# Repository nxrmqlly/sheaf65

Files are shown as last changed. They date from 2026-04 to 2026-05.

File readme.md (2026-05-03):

# sheaf65 🌊

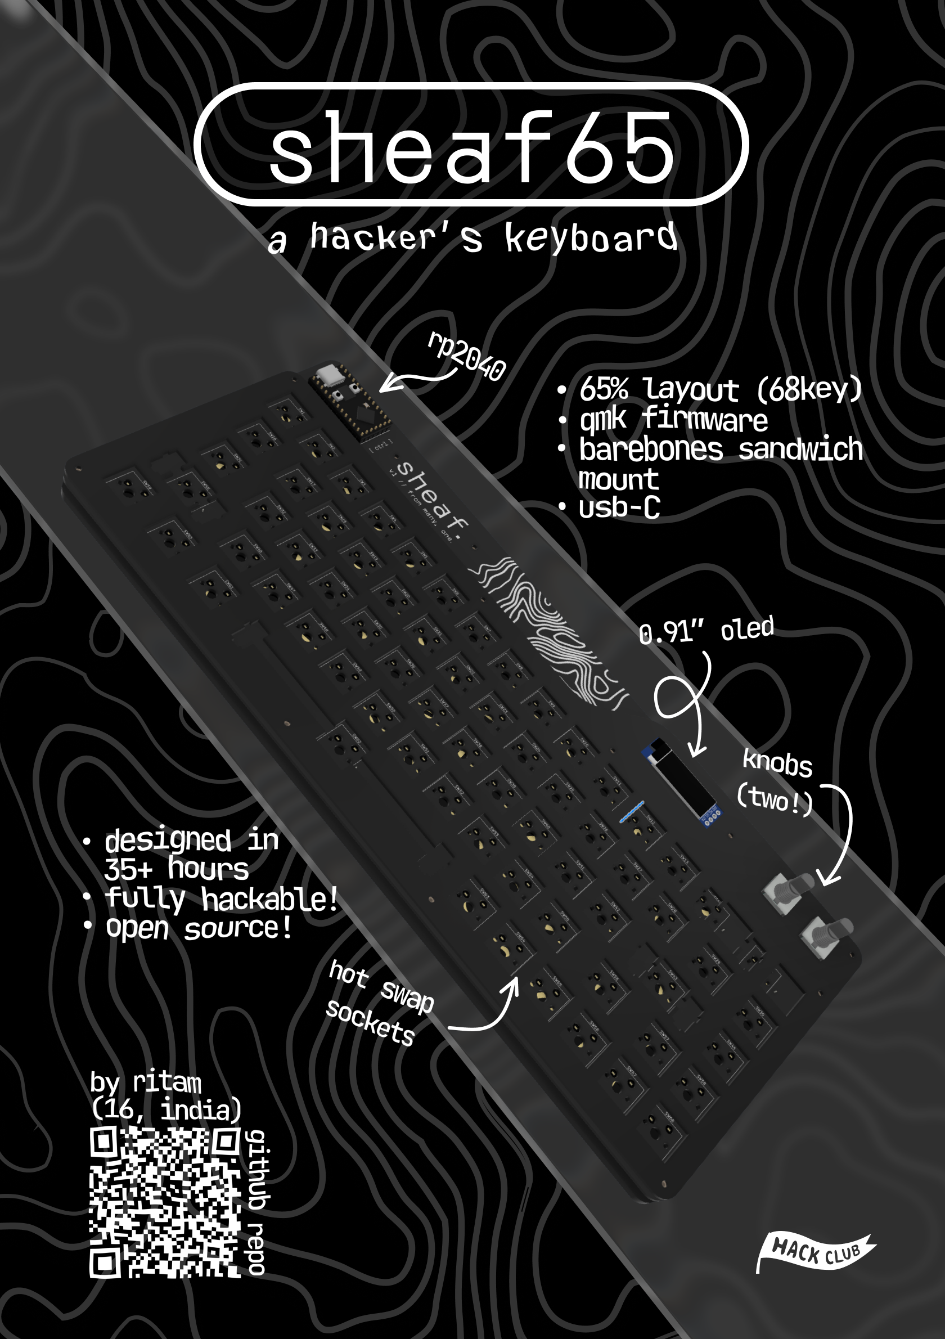
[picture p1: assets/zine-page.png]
hackclub magazine page


A barebones, hackable, opinionated, ansi 65% layout  keyboard. The `Backspace` key and the `Grave` key swapped due to personal preferences.

The Keyboard is designed to be very bare bones and it is basically 3 layers - The switchplate (top), The PCB (Middle),
and The Backplate (Bottom) - kind of like a sandwich mounted keyboard.

The switchplate ("plate") and the backplate are to be 3D printed and engineered.
The whole "sandwich" is held together with 10 M2x10mm brass spacers and one M2x6mm brass spacer.

I also took the liberty to add two knobs and an OLED display to the keyboard because... why not?

## TL;DR for busy people

A simple, hackable 65% keyboard
1. RP2040-powered
2. Fully Hotswap (TTC Pokayoke V2)
3. 0.91" OLED Screen
4. Dual Rotary Encoders (Knobs)
5. QMK firmware (VIA soon)
6. Sandwich Mounted (3-stacked-layer)

Built because I wanted something fun and unique... with knobs.

## Why?
I wanted a nice keyboard, and decided that making one for myself would be a fun challenge to pursue.
I wanted a unique yet sleek looking keyboard that somewhat resembles the idea of a through hole keybaord kit minus the ugly visible diodes.
Also, no such THT keyboard kit did hotswap sockets (I know the sockets are SMD but you get me) so there's that.

## Microcontroller / Devboard
I used an Generic ProMicro RP2040 chip which is basically an Pi RP2040 in a somewhat a ProMicro layout, I found it on robu and I thought it was perfect so I went with it!. 

The devboard is THT soldered and mounted onto the keyboard, in full display, sort of like nibble65 keyboard but horizontal.

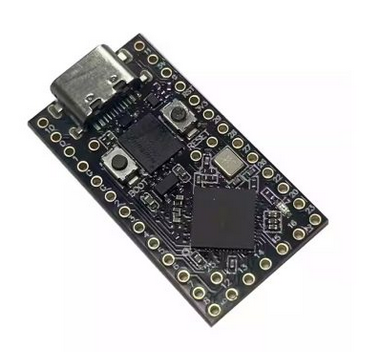
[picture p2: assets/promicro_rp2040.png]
generic promicro rp2040


## The PCB

The PCB was made in the best software ever (for legal reasons that's a joke) called **KiCad**, it was straightforward enough but I think a good software helps a ton! Also, I'm taking on SMD soldering by including TTC Pokayoke hotswap sockets in this!

Here are some screenshots:

| What | Image |
|---|---|
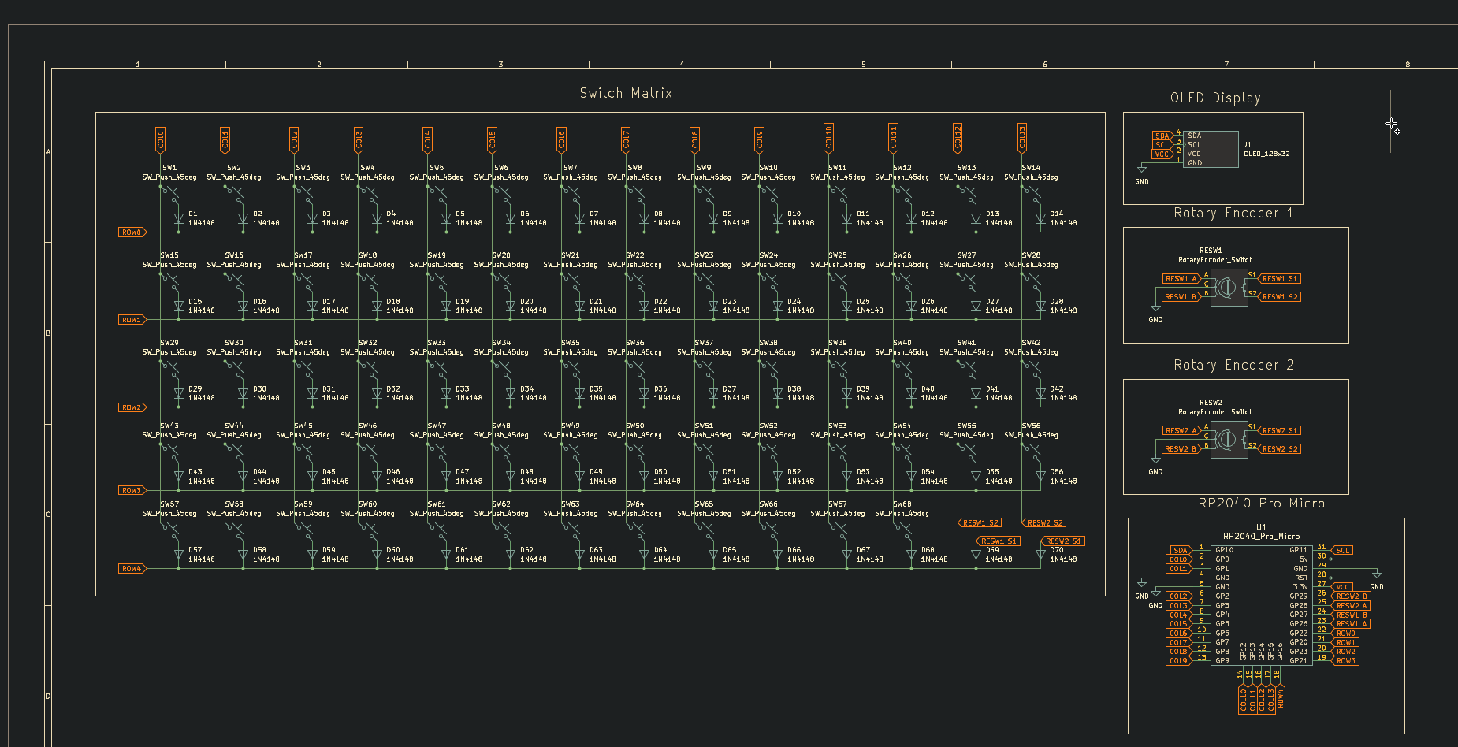
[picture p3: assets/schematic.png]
schematic
| Schematic | |
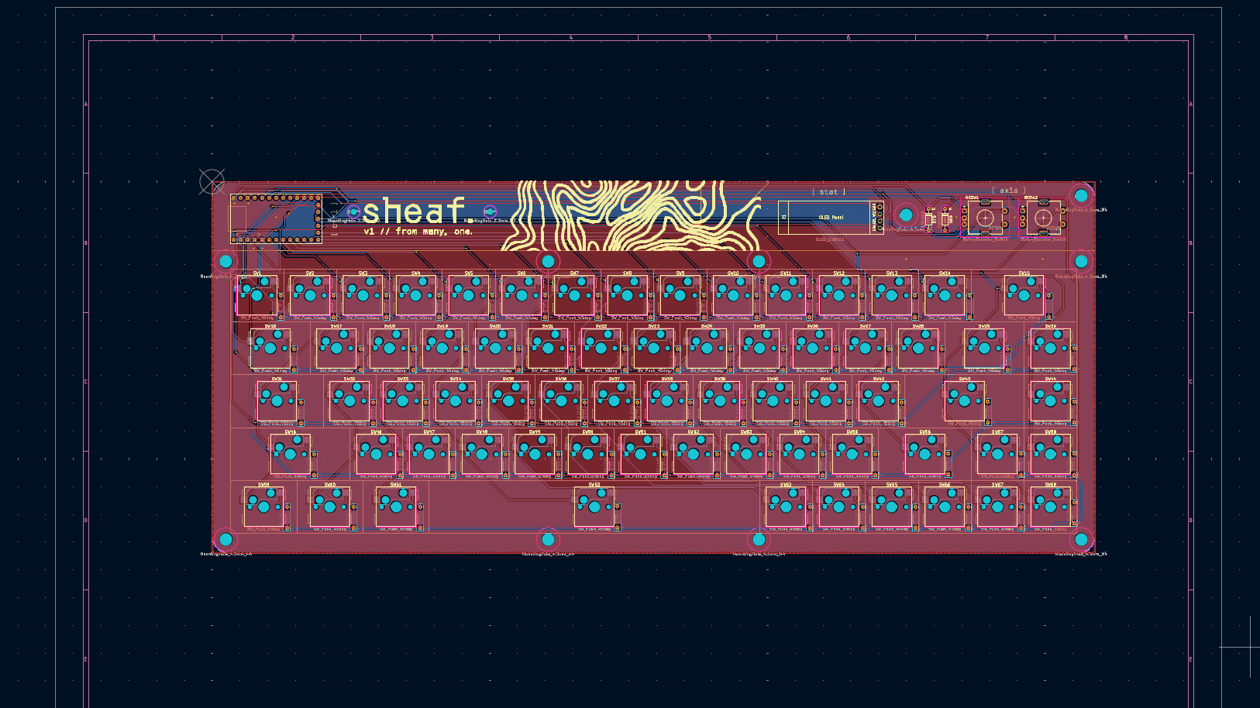
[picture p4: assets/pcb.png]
pcb
| PCB (B.silk hidden)| |
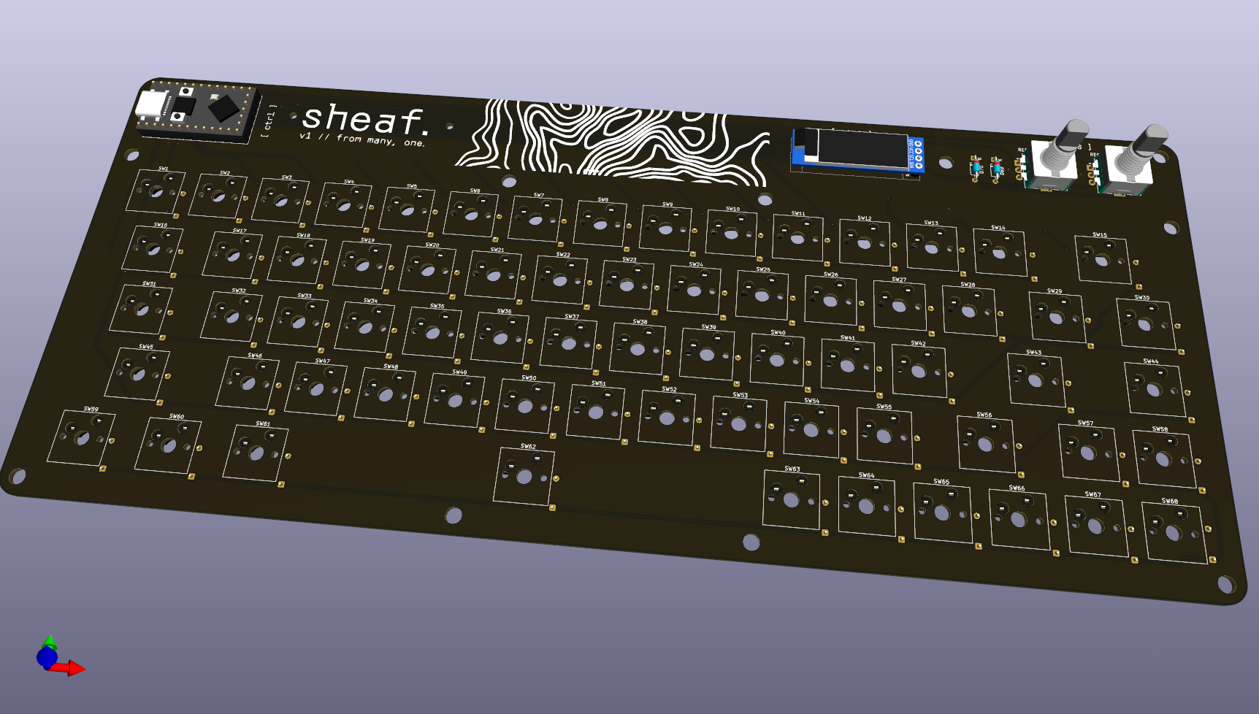
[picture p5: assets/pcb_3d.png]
pcb 3d render
| PCB 3D Model ||

## The "Case"

I designed the case in Autodesk Fusion (formerly Fusion360) - good software!
The case is not really a case, its just two plates, one backplate and one switchplate

| What | Image |
|---|---|
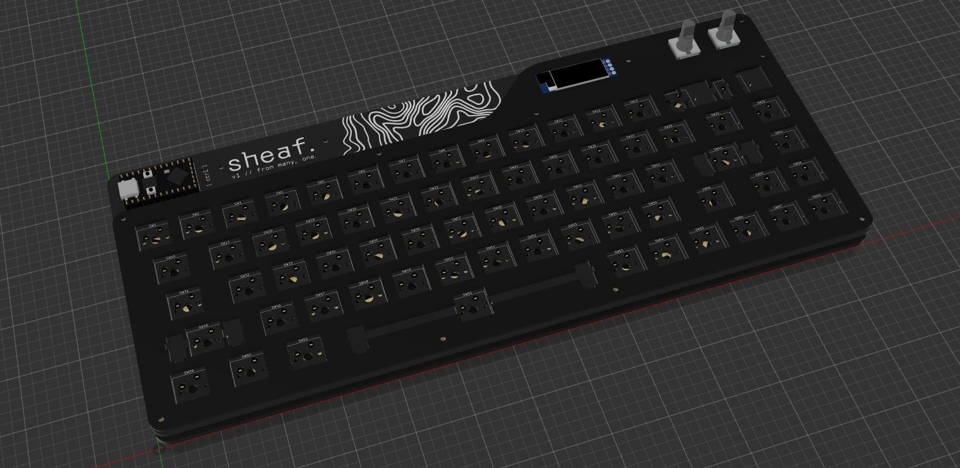
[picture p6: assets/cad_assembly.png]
keybaord CAD
| CAD Assembly | |

## WTF is that design? (Design Credits + more)

The inspiration for this kind of keyboard case (or the whole thing in general) comes from though-hole keyboard kits like:
- mercuito40 (for the switchplate and mounting)
- gingham65 (mounting)
- nibble65 (embracing the exposed MCU design)
- my wack brain (for two knobs)
- also thanks to [somepin](https://www.printables.com/@somepin) for the [3d printed keyboard feet](https://www.printables.com/model/876658-mechanical-keyboard-cone-feet/files)
- **Honorable mention:**
>*reviewer (#fallout-checkpoint): ...I also think this would look sick with under glow... maybe consider that*
>Yeah no, the keyboard was NoRGB by choice, I like NoRGB setups

However, I didn't really like the exposed ugly diodes on the top, so I opted for a neat silkscreen instead which I designed in **Figma** (I know it isnt the correct tool for the job but whatever really)

> (find the custom silkscreen footprints [here](./kicad/footprints/art.pretty/))

## Keyboard Parts

Straightforward really, the switches, keycaps - they're all personal preference, so, heres my preference:

1. **Switches**: Nothing really beats the **Keygeek x MZ Y3 Linear Switches** for me, they're the perfect mix of thock (not as much as the Y2) and just enough creamy sound
2. **Keycaps**: PBT Clone Keycaps, nothing technical here, just Cherry Profile because I'm boring.
3. **Stabilizers**: i may have cheaped out, but the **Durock Plate-Mount Stabilizers** will work out for me.
4. **Hotswap**: The PCB is designed for TTC Pokayoke V2 hotswap sockets, so customizability is infinite!
5. **The "Case"**: The Hardware/CAD directory has both KeyboardPlate and Backplate STEP files, with their _3DP suffixed variants which are meant for 3D printing as they are filleted.

But really though, switches and keycaps are very personal and well, I can't really decide for you but all I can say is that I saw a thousand videos before settline on what I did.

## Firmware

Nothing too fancy here, just QMK (I fought with qmk for HOURS)

I plan to add VIA support soon :tm:

## The BOM

I would create a markdown table but I'm lazy... full breakdown in
[bom.csv here](./Hardware/bom/bom.csv)

> Costs \~₹10619 (~$124)

Somehow the BOM was fun to write!

## How to build it IRL

1. Spend some $$$ to get the parts from the BOM
2. Get your PCB fabricated and case 3D printed or machined (if 3D printing use the _3DP suffixed CAD files)
3. Solder Hotswap sockets on the back of the PCB and the through hole diodes too.
4. Solder header pins onto the MCU and that onto the PCB
5. Secure the 6mm stanoffs onto the countersunk holes on the backplate and the 10mm standoffs on the rest of the holes
6. Connect your switches to the plate and PCB
7. Slide the PCB into the standoffs and secure the plate with screws.

## License
The hardware (PCB, CAD Parts, Footprints) are licensed under `CERN Open Hardware Licence Version 2 - Strongly Reciprocal` 
which means, you're all-right to copy my work and use it in yours but you must disclose your source code and project files to opensource platforms if you use my work. See [LICENSE](LICENSE)

Firmware is QMK so, it is licensed under `GNU General Public License v2` (see [LICENSE-GPL](LICENSE-GPL))

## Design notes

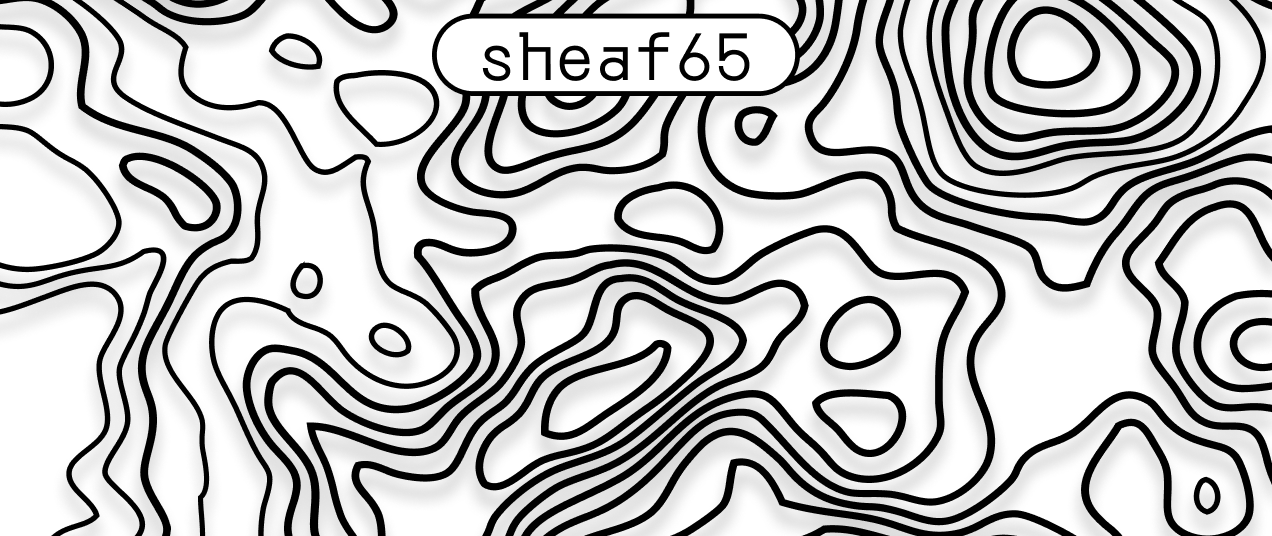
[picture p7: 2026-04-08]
assets/art/back_design_new.png

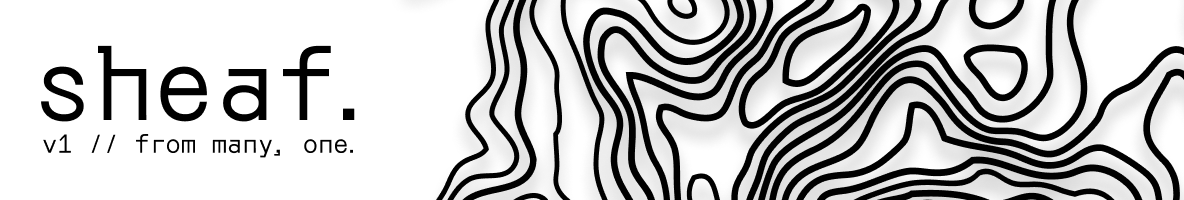
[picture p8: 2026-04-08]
assets/art/top_design.png

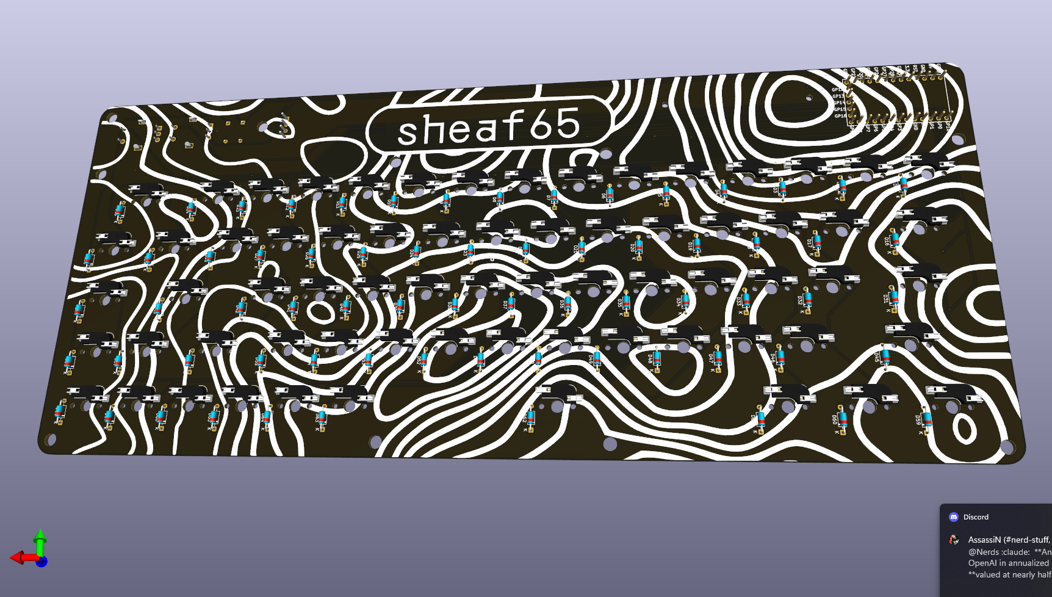
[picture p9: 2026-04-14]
assets/pcb_3d_back.png

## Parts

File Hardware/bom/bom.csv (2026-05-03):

Category | Item | Spec | Brand | Quantity | Cost (INR) | Cost (USD) | Link
PCB | MCU Board | ProMicro RP2040 | Generic | 1 | 303 | ~$3.26 | https://robu.in/product/promicro-rp2040-blackboard-proxy/
PCB | THT Diodes | 1N4148 DO-35 | Generic | 100 | 96 | ~$1.03 | https://robu.in/product/1n4148-1w-zener-diode-pack-of-50/
PCB | Rotary Encoder | EC11 10K | Generic | 2 | 172 | ~$1.85 | https://www.amazon.in/dp/B0888RWNM1
PCB | OLED Display | SSD1306 I2C 0.91" | Generic | 1 | 157 | ~$1.69 | https://robu.in/product/blue-oled-display-module
PCB | Male Header | Male to Male Header 10u | Generic | 1 | 9 | ~$0.1 | https://robu.in/product/2-54mm-1x40-pin-male-single-row-smt-header-strip-pack-of-5/
PCB | Hotswap Socket | TTC Pokayoke V2 Socket | TTC | 68 | 680 | ~$7.31 | https://meckeys.com/shop/accessories/keyboard-accessories/key-switches/kailh-hot-swap-socket/
PCB | Fabrication | 2-layer, FR4, 1.6mm | JLCPCB | 5 | 4,800 | ~$51.61 | https://jlcpcb.com/
Mounting | Phillips Screw | M2 x 4mm | OnlyScrews | 2 | 7.6 | ~$0.08 | https://onlyscrews.in/products/m2-x-4mm-phillips-round-head-laptop-screw
Mounting | Phillips Screw | M2 x 5mm | OnlyScrews | 12 | 48 | ~$0.52 | https://onlyscrews.in/products/m2-x-4mm-phillips-round-head-laptop-screw-dia-2mm-length-5mm
Mounting | Phillips Screw | M2 x 8mm | OnlyScrews | 10 | 44 | ~$0.47 | https://onlyscrews.in/products/m2-x-8mm-phillips-round-head-laptop-screw-1
Mounting | Phillips Screw | M4 x 8mm | OnlyScrews | 2 | 4.4 | ~$0.05 | https://onlyscrews.in/products/phillips-pan-head-m4-x-8mm-pack-of-20
Mounting | Threaded Insert | M4 x 4mm | OnlyScrews | 2 | 6.4 | ~$0.07 | https://onlyscrews.in/products/m4-x-4mm-brass-threaded-inserts-2
Mounting | Spacer | Brass Spacer M2 x 10mm | OnlyScrews | 10 | 56 | ~$0.6 | https://onlyscrews.in/products/m2-x-10mm-female-to-female-brass-with-nickel-plating-hex-threaded-standoff-spacer
Mounting | Spacer | Brass Spacer M2 x 6mm | OnlyScrews | 2 | 8 | ~$0.09 | https://onlyscrews.in/products/m2-x-6mm-female-to-female-brass-with-nickel-plating-hex-threaded-standoff-spacer
Body | Rubber Feet | 8mm Self Adhesive | Generic | 100 | 189 | ~$2.03 | https://www.amazon.in/Miramar-Adhesive-Non-Slip-Furniture-Hemispherical/dp/B0BLN4TCPT
Body | Plate, Backplate | 3D printed | Robu.in FDM | 1 | 990 | ~$10.65 | https://robu.in/product/3d-printing-service1
Keyboard Part | Switches | Y3 Linear Switches | Keygeek MZ Studio | 70 | 1,680 | ~$18.06 | https://keyora.store/products/keygeek-y3
Keyboard Part | Keycaps | Cherry PBT Keycaps | CuriosityCaps | 1 | 1800 | ~$19.35 | https://curiositycaps.in/products/grey-animals-party-big-font-cherry-pbt-keycaps
Keyboard Part | Stabilizers | Plate Mount Stabilizer Set | Durock | 1 | 380 | ~$4.09 | https://www.genesispc.in/products/durock-plate-mount-stabilizers-6-25u-4x2u-black
Shipping |  |  |  |  | 182 | ~$1.96
TOTAL |  |  |  |  | 11612.4 | ~$124.86

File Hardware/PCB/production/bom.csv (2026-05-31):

Designator | Footprint | Quantity | Value | LCSC Part #
D1, D10, D11, D12, D13, D14, D15, D16, D17, D18, D19, D2, D20, D21, D22, D23, D24, D25, D26, D27, D28, D29, D3, D30, D31, D32, D33, D34, D35, D36, D37, D38, D39, D4, D40, D41, D42, D43, D44, D45, D46, D47, D48, D49, D5, D50, D51, D52, D53, D54, D55, D56, D57, D58, D59, D6, D60, D61, D62, D63, D64, D65, D66, D67, D68, D69, D7, D70, D8, D9 | D_DO-35_SOD27_P7.62mm_Horizontal | 70 | 1N4148
J1 | SSD1306-0.91-OLED-4pin-128x32 | 1 | OLED_128x32
RESW1, RESW2 | RotaryEncoder_Alps_EC11E-Switch_Vertical_H20mm | 2 | RotaryEncoder_Switch
SW1, SW10, SW11, SW12, SW13, SW15, SW17, SW18, SW19, SW2, SW20, SW21, SW22, SW23, SW24, SW25, SW26, SW27, SW28, SW3, SW30, SW32, SW33, SW34, SW35, SW36, SW37, SW38, SW39, SW4, SW40, SW41, SW42, SW44, SW46, SW47, SW48, SW49, SW5, SW50, SW51, SW52, SW53, SW54, SW55, SW57, SW58, SW6, SW63, SW64, SW65, SW66, SW67, SW68, SW7, SW8, SW9 | SW_Hotswap_Kailh_MX_1.00u | 57 | SW_Push_45deg
SW14 | SW_Hotswap_Kailh_MX_2.00u | 1 | SW_Push_45deg
SW16, SW29 | SW_Hotswap_Kailh_MX_1.50u | 2 | SW_Push_45deg
SW31, SW56 | SW_Hotswap_Kailh_MX_1.75u | 2 | SW_Push_45deg
SW43, SW45 | SW_Hotswap_Kailh_MX_2.25u | 2 | SW_Push_45deg
SW59, SW60, SW61 | SW_Hotswap_Kailh_MX_1.25u | 3 | SW_Push_45deg
SW62 | SW_Hotswap_Kailh_MX_6.25u | 1 | SW_Push_45deg
U1 | RP2040_Pro_Micro | 1 | RP2040_Pro_Micro

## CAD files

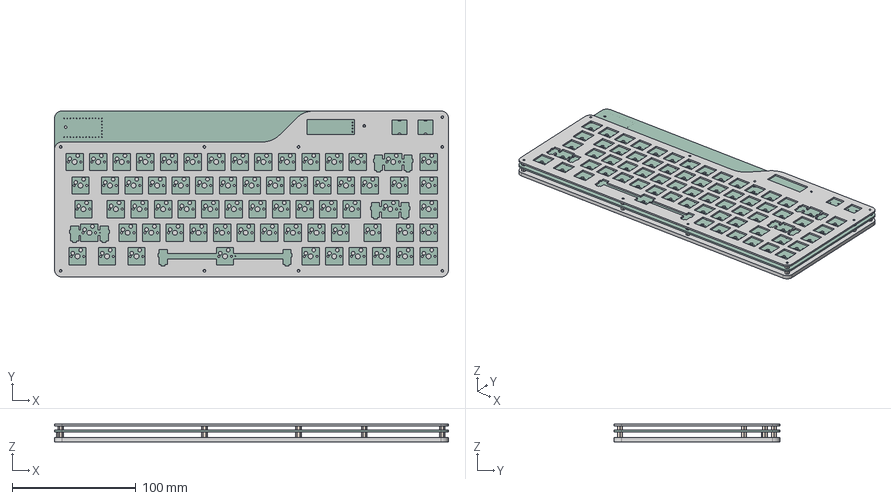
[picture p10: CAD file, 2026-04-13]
Hardware/CAD/Assembly.step
318.0 x 134.0 x 14.5 mm

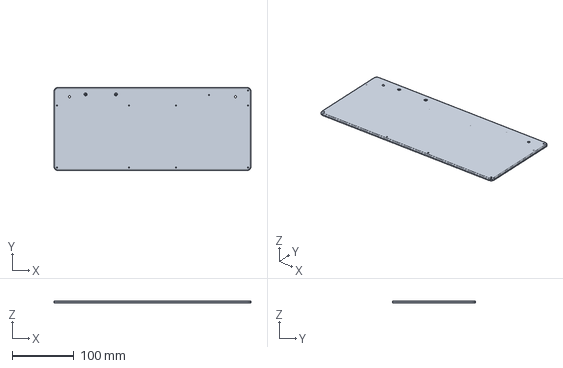
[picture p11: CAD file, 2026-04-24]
Hardware/CAD/Backplate_3DP.step
318.0 x 134.0 x 3.50 mm

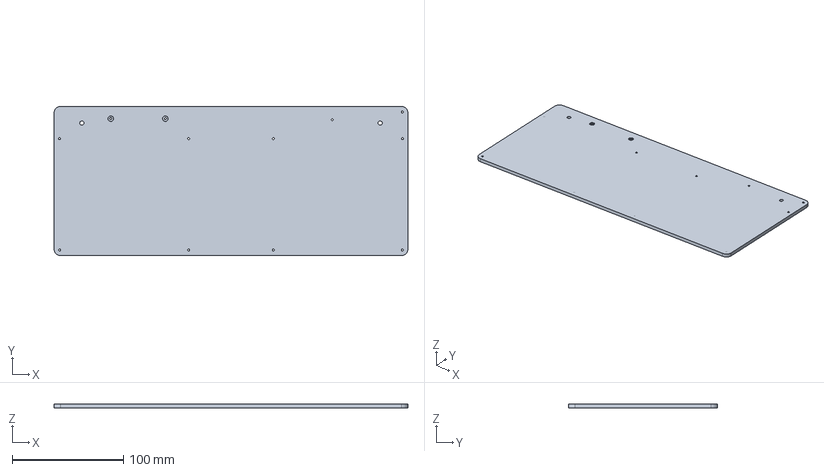
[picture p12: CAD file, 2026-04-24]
Hardware/CAD/Backplate.step
318.0 x 134.0 x 3.50 mm

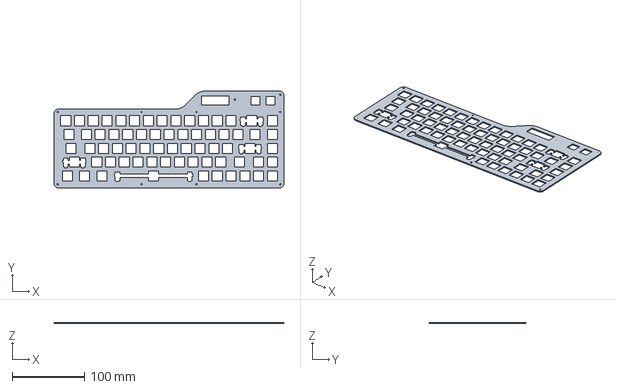
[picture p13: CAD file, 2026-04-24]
Hardware/CAD/KeyboardPlate.step
318.0 x 134.0 x 1.50 mm

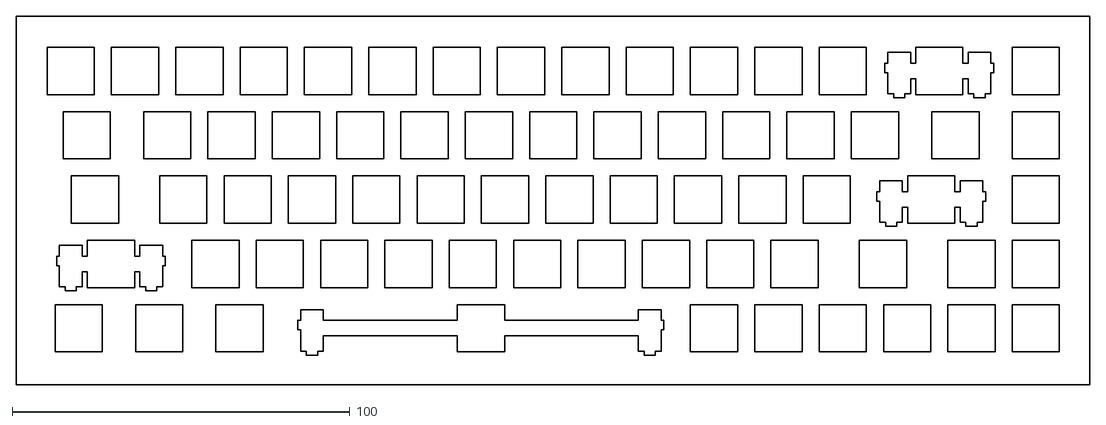
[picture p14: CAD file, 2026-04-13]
Hardware/CAD/plate.dxf
318.0 x 109.0

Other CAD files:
Hardware/CAD/KeyboardPlate_3DP.step

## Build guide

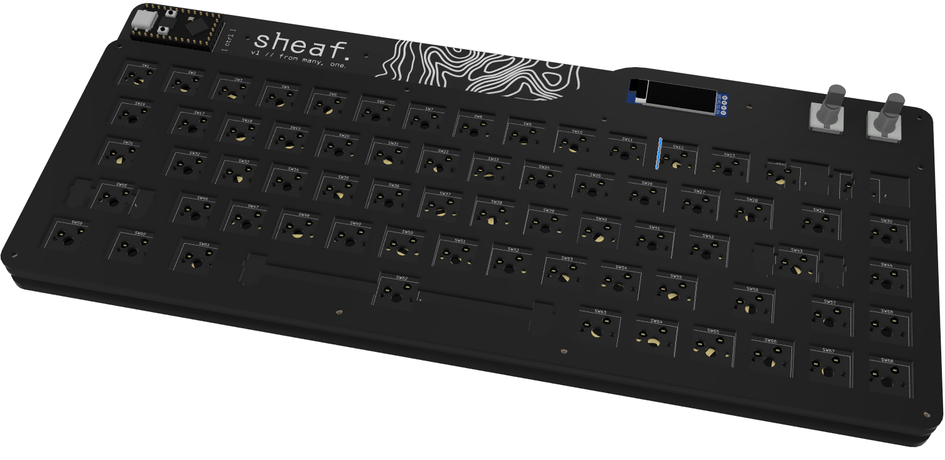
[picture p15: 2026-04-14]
assets/assembly_t.png

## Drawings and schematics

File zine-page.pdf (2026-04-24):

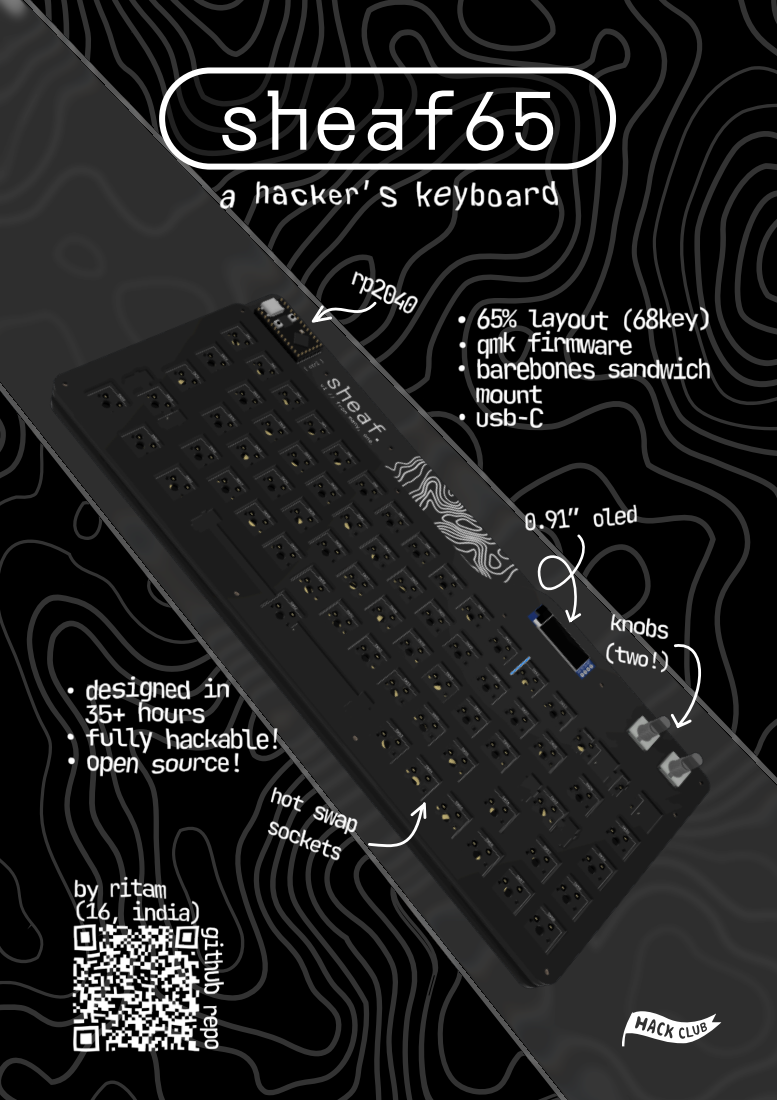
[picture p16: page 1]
sheaf65

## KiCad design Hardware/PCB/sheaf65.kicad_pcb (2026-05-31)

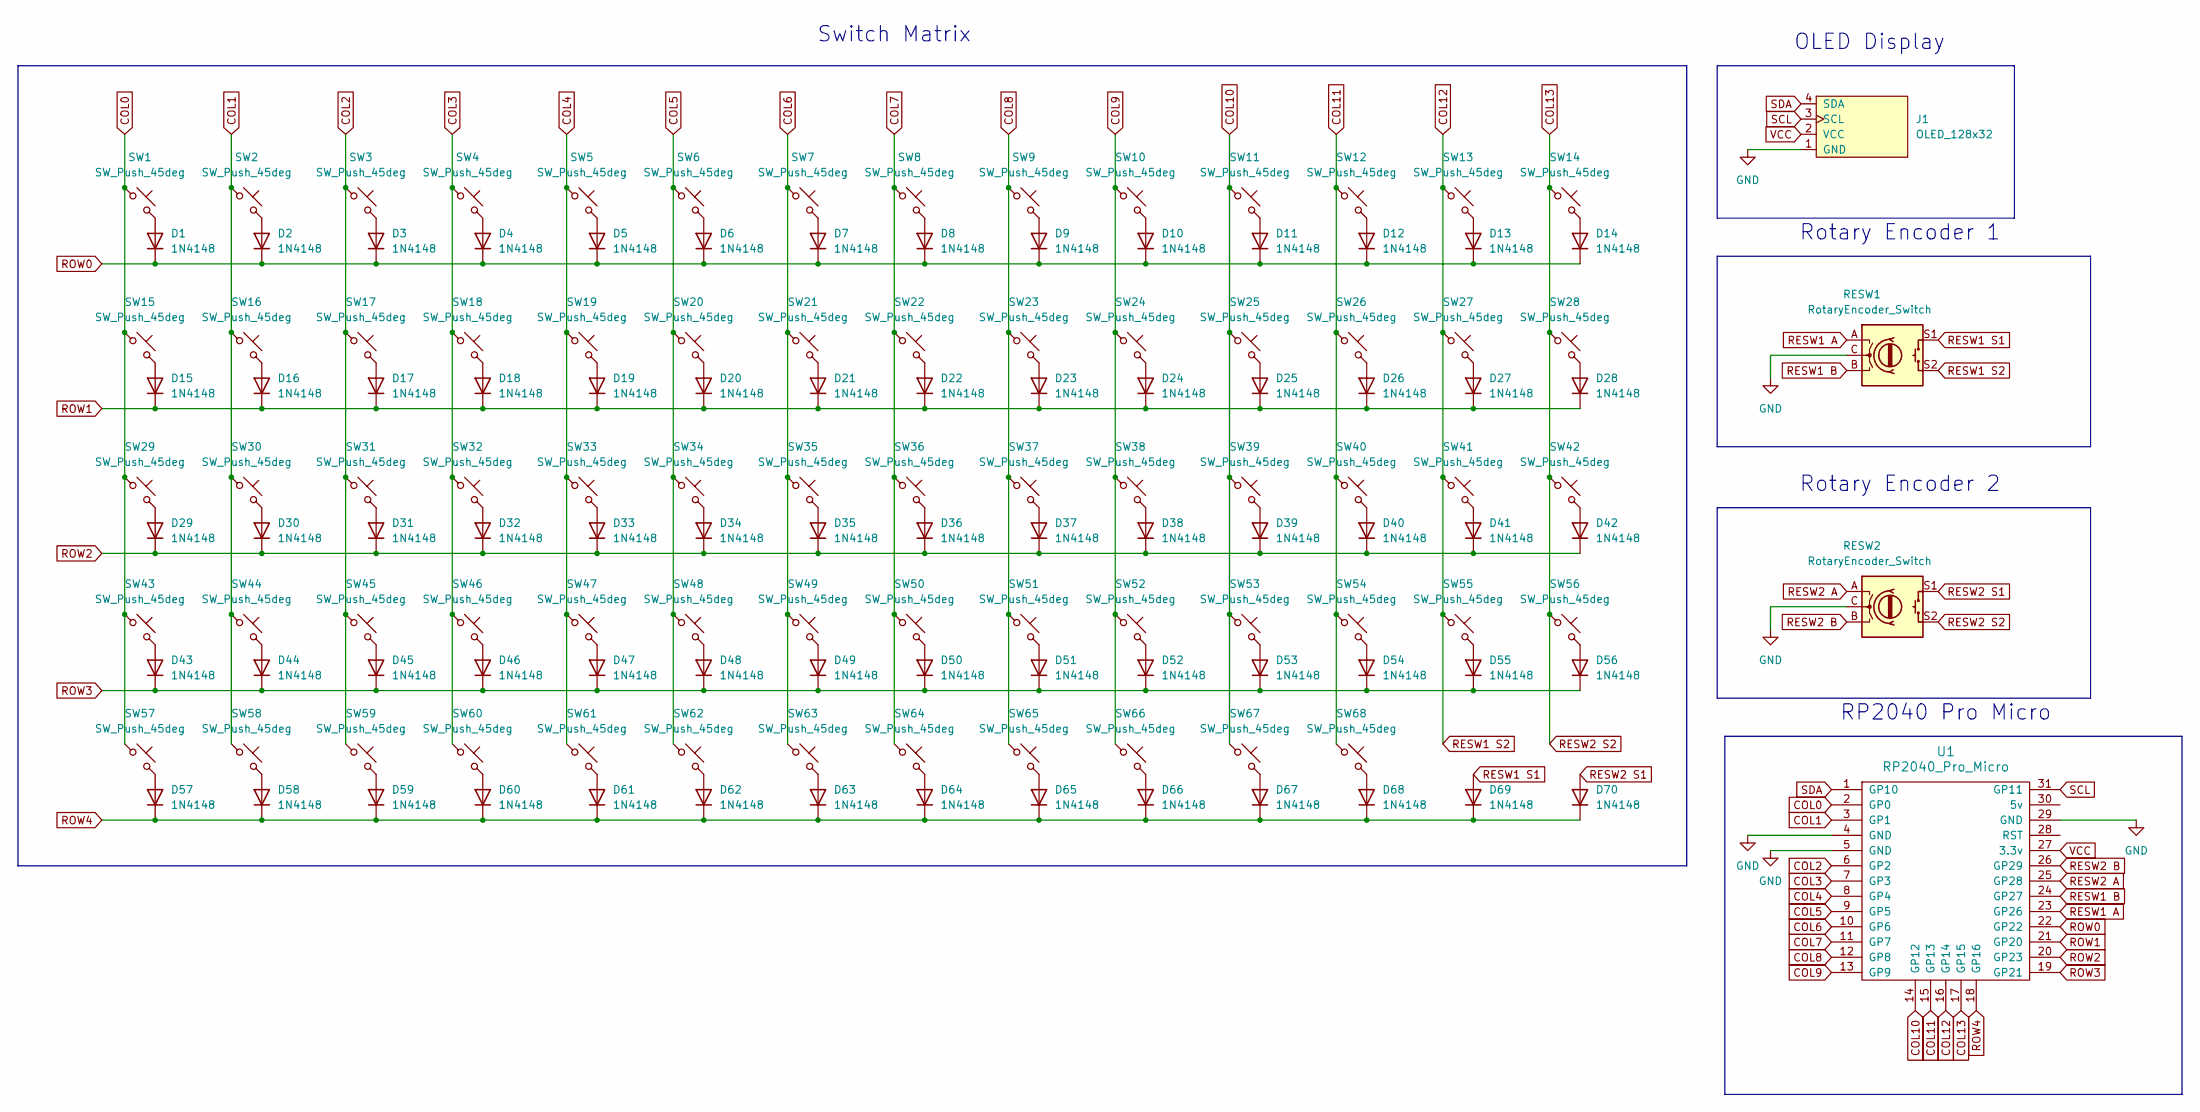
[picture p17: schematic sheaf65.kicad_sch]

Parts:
D1, D2, D3, D4, D5, D6, D7, D8, D9, D10, D11, D12, D13, D14, D15, D16, D17, D18, D19, D20, D21, D22, D23, D24, D25, D26, D27, D28, D29, D30, D31, D32, D33, D34, D35, D36, D37, D38, D39, D40, D41, D42, D43, D44, D45, D46, D47, D48, D49, D50, D51, D52, D53, D54, D55, D56, D57, D58, D59, D60, D61, D62, D63, D64, D65, D66, D67, D68, D69, D70: 1N4148; D_DO-35_SOD27_P7.62mm_Horizontal
J1: OLED_128x32; SSD1306-0.91-OLED-4pin-128x32
RESW1, RESW2: RotaryEncoder_Switch; RotaryEncoder_Alps_EC11E-Switch_Vertical_H20mm
SW1, SW2, SW3, SW4, SW5, SW6, SW7, SW8, SW9, SW10, SW11, SW12, SW13, SW15, SW17, SW18, SW19, SW20, SW21, SW22, SW23, SW24, SW25, SW26, SW27, SW28, SW30, SW32, SW33, SW34, SW35, SW36, SW37, SW38, SW39, SW40, SW41, SW42, SW44, SW46, SW47, SW48, SW49, SW50, SW51, SW52, SW53, SW54, SW55, SW57, SW58, SW63, SW64, SW65, SW66, SW67, SW68: SW_Push_45deg; SW_Hotswap_Kailh_MX_1.00u
SW14: SW_Push_45deg; SW_Hotswap_Kailh_MX_2.00u
SW16, SW29: SW_Push_45deg; SW_Hotswap_Kailh_MX_1.50u
SW31, SW56: SW_Push_45deg; SW_Hotswap_Kailh_MX_1.75u
SW43, SW45: SW_Push_45deg; SW_Hotswap_Kailh_MX_2.25u
SW59, SW60, SW61: SW_Push_45deg; SW_Hotswap_Kailh_MX_1.25u
SW62: SW_Push_45deg; SW_Hotswap_Kailh_MX_6.25u
U1: RP2040_Pro_Micro

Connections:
COL0: SW1.1, SW15.1, SW29.1, SW43.1, SW57.1, U1.2 (GP0)
COL1: SW2.1, SW16.1, SW30.1, SW44.1, SW58.1, U1.3 (GP1)
COL2: SW3.1, SW17.1, SW31.1, SW45.1, SW59.1, U1.6 (GP2)
COL3: SW4.1, SW18.1, SW32.1, SW46.1, SW60.1, U1.7 (GP3)
COL4: SW5.1, SW19.1, SW33.1, SW47.1, SW61.1, U1.8 (GP4)
COL5: SW6.1, SW20.1, SW34.1, SW48.1, SW62.1, U1.9 (GP5)
COL6: SW7.1, SW21.1, SW35.1, SW49.1, SW63.1, U1.10 (GP6)
COL7: SW8.1, SW22.1, SW36.1, SW50.1, SW64.1, U1.11 (GP7)
COL8: SW9.1, SW23.1, SW37.1, SW51.1, SW65.1, U1.12 (GP8)
COL9: SW10.1, SW24.1, SW38.1, SW52.1, SW66.1, U1.13 (GP9)
COL10: SW11.1, SW25.1, SW39.1, SW53.1, SW67.1, U1.14 (GP12)
COL11: SW12.1, SW26.1, SW40.1, SW54.1, SW68.1, U1.15 (GP13)
COL12: RESW1.S2, SW13.1, SW27.1, SW41.1, SW55.1, U1.16 (GP14)
COL13: RESW2.S2, SW14.1, SW28.1, SW42.1, SW56.1, U1.17 (GP15)
GND: J1.1 (GND), RESW1.C, RESW2.C, U1.4 (GND), U1.5 (GND), U1.29 (GND)
unnamed: D1.2 (A), SW1.2
unnamed: D2.2 (A), SW2.2
unnamed: D3.2 (A), SW3.2
unnamed: D4.2 (A), SW4.2
unnamed: D5.2 (A), SW5.2
unnamed: D6.2 (A), SW6.2
unnamed: D7.2 (A), SW7.2
unnamed: D8.2 (A), SW8.2
unnamed: D9.2 (A), SW9.2
unnamed: D10.2 (A), SW10.2
unnamed: D11.2 (A), SW11.2
unnamed: D12.2 (A), SW12.2
unnamed: D13.2 (A), SW13.2
unnamed: D14.2 (A), SW14.2
unnamed: D15.2 (A), SW15.2
unnamed: D16.2 (A), SW16.2
unnamed: D17.2 (A), SW17.2
unnamed: D18.2 (A), SW18.2
unnamed: D19.2 (A), SW19.2
unnamed: D20.2 (A), SW20.2
unnamed: D21.2 (A), SW21.2
unnamed: D22.2 (A), SW22.2
unnamed: D23.2 (A), SW23.2
unnamed: D24.2 (A), SW24.2
unnamed: D25.2 (A), SW25.2
unnamed: D26.2 (A), SW26.2
unnamed: D27.2 (A), SW27.2
unnamed: D28.2 (A), SW28.2
unnamed: D29.2 (A), SW29.2
unnamed: D30.2 (A), SW30.2
unnamed: D31.2 (A), SW31.2
unnamed: D32.2 (A), SW32.2
unnamed: D33.2 (A), SW33.2
unnamed: D34.2 (A), SW34.2
unnamed: D35.2 (A), SW35.2
unnamed: D36.2 (A), SW36.2
unnamed: D37.2 (A), SW37.2
unnamed: D38.2 (A), SW38.2
unnamed: D39.2 (A), SW39.2
unnamed: D40.2 (A), SW40.2
unnamed: D41.2 (A), SW41.2
unnamed: D42.2 (A), SW42.2
unnamed: D43.2 (A), SW43.2
unnamed: D44.2 (A), SW44.2
unnamed: D45.2 (A), SW45.2
unnamed: D46.2 (A), SW46.2
unnamed: D47.2 (A), SW47.2
unnamed: D48.2 (A), SW48.2
unnamed: D49.2 (A), SW49.2
unnamed: D50.2 (A), SW50.2
unnamed: D51.2 (A), SW51.2
unnamed: D52.2 (A), SW52.2
unnamed: D53.2 (A), SW53.2
unnamed: D54.2 (A), SW54.2
unnamed: D55.2 (A), SW55.2
unnamed: D56.2 (A), SW56.2
unnamed: D57.2 (A), SW57.2
unnamed: D58.2 (A), SW58.2
unnamed: D59.2 (A), SW59.2
unnamed: D60.2 (A), SW60.2
unnamed: D61.2 (A), SW61.2
unnamed: D62.2 (A), SW62.2
unnamed: D63.2 (A), SW63.2
unnamed: D64.2 (A), SW64.2
unnamed: D65.2 (A), SW65.2
unnamed: D66.2 (A), SW66.2
unnamed: D67.2 (A), SW67.2
unnamed: D68.2 (A), SW68.2
RESW1 A: RESW1.A, U1.23 (GP26)
RESW1 B: RESW1.B, U1.24 (GP27)
RESW1 S1: D69.2 (A), RESW1.S1
RESW2 A: RESW2.A, U1.25 (GP28)
RESW2 B: RESW2.B, U1.26 (GP29)
RESW2 S1: D70.2 (A), RESW2.S1
ROW0: D1.1 (K), D2.1 (K), D3.1 (K), D4.1 (K), D5.1 (K), D6.1 (K), D7.1 (K), D8.1 (K), D9.1 (K), D10.1 (K), D11.1 (K), D12.1 (K), D13.1 (K), D14.1 (K), U1.22 (GP22)
ROW1: D15.1 (K), D16.1 (K), D17.1 (K), D18.1 (K), D19.1 (K), D20.1 (K), D21.1 (K), D22.1 (K), D23.1 (K), D24.1 (K), D25.1 (K), D26.1 (K), D27.1 (K), D28.1 (K), U1.21 (GP20)
ROW2: D29.1 (K), D30.1 (K), D31.1 (K), D32.1 (K), D33.1 (K), D34.1 (K), D35.1 (K), D36.1 (K), D37.1 (K), D38.1 (K), D39.1 (K), D40.1 (K), D41.1 (K), D42.1 (K), U1.20 (GP23)
ROW3: D43.1 (K), D44.1 (K), D45.1 (K), D46.1 (K), D47.1 (K), D48.1 (K), D49.1 (K), D50.1 (K), D51.1 (K), D52.1 (K), D53.1 (K), D54.1 (K), D55.1 (K), D56.1 (K), U1.19 (GP21)
ROW4: D57.1 (K), D58.1 (K), D59.1 (K), D60.1 (K), D61.1 (K), D62.1 (K), D63.1 (K), D64.1 (K), D65.1 (K), D66.1 (K), D67.1 (K), D68.1 (K), D69.1 (K), D70.1 (K), U1.18 (GP16)
SCL: J1.3 (SCL), U1.31 (GP11)
SDA: J1.4 (SDA), U1.1 (GP10)
VCC: J1.2 (VCC), U1.27 (3.3v)

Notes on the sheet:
RP2040 Pro Micro
Rotary Encoder 2
Switch Matrix
Rotary Encoder 1
OLED Display

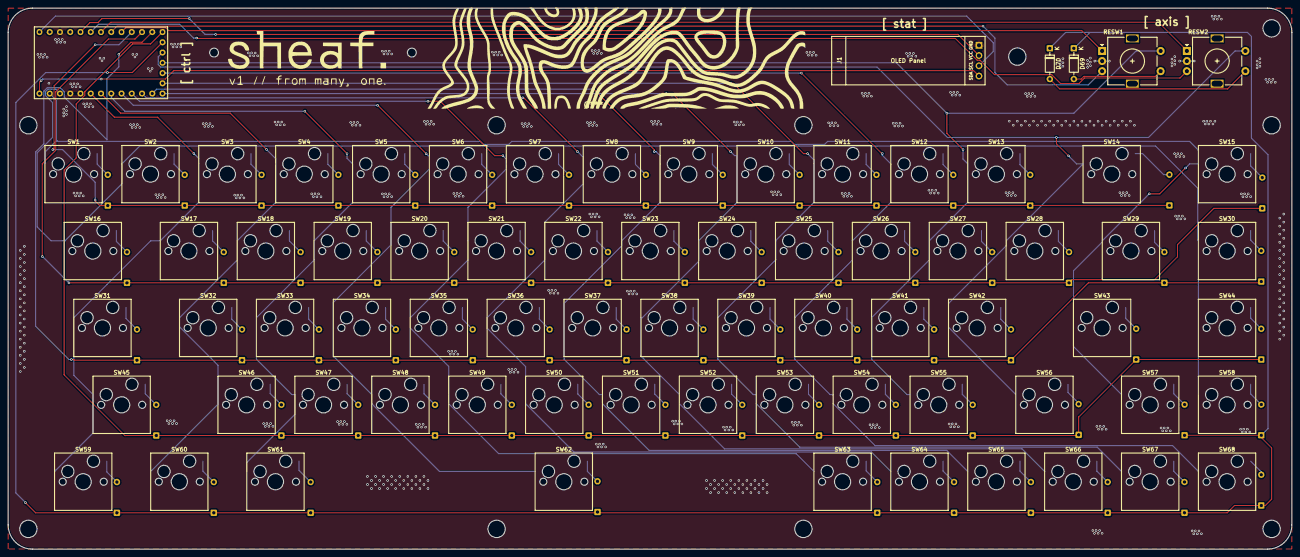
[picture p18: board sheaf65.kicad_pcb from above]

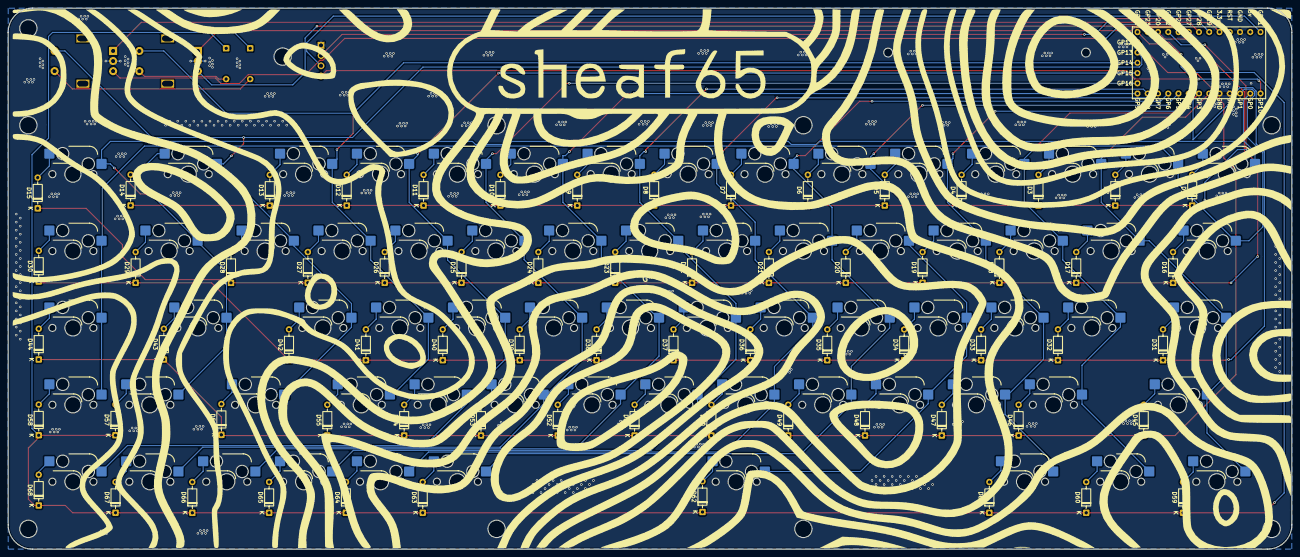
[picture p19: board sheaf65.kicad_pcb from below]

Board: 2 copper layers, 318.0 x 134.0 mm, 142 parts (68 on the bottom side), 97 nets.

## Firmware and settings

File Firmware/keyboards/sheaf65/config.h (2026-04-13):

#pragma once


#define I2C_DRIVER I2CD1
#define I2C1_SDA_PIN GP10
#define I2C1_SCL_PIN GP11

// OLED
#define OLED_DISPLAY_128X32
#define OLED_DRIVER_ENABLE

#define ENCODER_RESOLUTION 4
#define ENCODER_A_PINS {GP26, GP28}
#define ENCODER_B_PINS {GP27, GP29}

// Tapping time term || mod-tap keys (ms)
#define TAPPING_TERM 200

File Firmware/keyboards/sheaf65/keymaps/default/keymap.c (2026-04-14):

// Copyright 2023 QMK
// SPDX-License-Identifier: GPL-2.0-or-later

#include "quantum.h"
#include QMK_KEYBOARD_H

enum layers {
    _BASE,
    _FN
};

const uint16_t PROGMEM keymaps[][MATRIX_ROWS][MATRIX_COLS] = {
    /*
     * ┌───┬───┬───┬───┬───┬───┬───┬───┬───┬───┬───┬───┬───┬───┬───────┐
     * │Esc│ 1 │ 2 │ 3 │ 4 │ 5 │ 6 │ 7 │ 8 │ 9 │ 0 │ - │ = │ ` │ BkSpc │
     * ├───┴─┬─┴─┬─┴─┬─┴─┬─┴─┬─┴─┬─┴─┬─┴─┬─┴─┬─┴─┬─┴─┬─┴─┬─┴─┬─┴───┬───┤
     * │ Tab │ Q │ W │ E │ R │ T │ Y │ U │ I │ O │ P │ [ │ ] │  \  │Del│
     * ├─────┴┬──┴┬──┴┬──┴┬──┴┬──┴┬──┴┬──┴┬──┴┬──┴┬──┴┬──┴┬──┴─────┼───┤
     * │ Caps │ A │ S │ D │ F │ G │ H │ J │ K │ L │ ; │ ' │  Enter │PgU│
     * ├──────┴─┬─┴─┬─┴─┬─┴─┬─┴─┬─┴─┬─┴─┬─┴─┬─┴─┬─┴─┬─┴─┬─┴────┬───┼───┤
     * │ Shift  │ Z │ X │ C │ V │ B │ N │ M │ , │ . │ / │ Shift│ ↑ │PgD│ *Knobs
     * ├────┬───┴┬──┴─┬─┴───┴───┴───┴───┴───┴──┬┴──┬┴──┬┴──┬───┼───┼───┼───┬───┐
     * │Ctrl│GUI │Alt │                        │Alt│ Fn│Ctl│ ← │ ↓ │ → │Mut│Ply│
     * └────┴────┴────┴────────────────────────┴───┴───┴───┴───┴───┴───┴───┴───┘
     */
    [_BASE] = LAYOUT_65_ansi(
        KC_ESC,  KC_1,    KC_2,    KC_3,    KC_4,    KC_5,    KC_6,    KC_7,    KC_8,    KC_9,    KC_0,    KC_MINS, KC_EQL,  KC_GRV, KC_BSPC,
        KC_TAB,  KC_Q,    KC_W,    KC_E,    KC_R,    KC_T,    KC_Y,    KC_U,    KC_I,    KC_O,    KC_P,    KC_LBRC, KC_RBRC, KC_BSLS, KC_DEL,
        KC_CAPS, KC_A,    KC_S,    KC_D,    KC_F,    KC_G,    KC_H,    KC_J,    KC_K,    KC_L,    KC_SCLN, KC_QUOT,          KC_ENT,  KC_PGUP,
        KC_LSFT,          KC_Z,    KC_X,    KC_C,    KC_V,    KC_B,    KC_N,    KC_M,    KC_COMM, KC_DOT,  KC_SLSH, KC_RSFT, KC_UP,   KC_PGDN,
        KC_LCTL, KC_LGUI, KC_LALT,                            KC_SPC,                    KC_RALT, MO(1),   KC_RCTL, KC_LEFT, KC_DOWN, KC_RGHT, KC_MUTE, KC_MPLY
    ),

    /*
     * ┌───┬───┬───┬───┬───┬───┬───┬───┬───┬───┬───┬───┬───┬───┬───────┐
     * │   │F1 │F2 │F3 │F4 │F5 │F6 │F7 │F8 │F9 │F10│F11│F12│   │       │
     * ├───┴─┬─┴─┬─┴─┬─┴─┬─┴─┬─┴─┬─┴─┬─┴─┬─┴─┬─┴─┬─┴─┬─┴─┬─┴─┬─┴───┬───┤
     * │     │   │   │   │   │   │   │   │   │   │   │PSc│Scr│Pause│Hom│
     * ├─────┴┬──┴┬──┴┬──┴┬──┴┬──┴┬──┴┬──┴┬──┴┬──┴┬──┴┬──┴┬──┴─────┼───┤
     * │      │   │   │   │   │   │   │   │   │   │   │Ins│        │End│
     * ├──────┴─┬─┴─┬─┴─┬─┴─┬─┴─┬─┴─┬─┴─┬─┴─┬─┴─┬─┴─┬─┴─┬─┴────┬───┼───┤
     * │        │   │   │   │   │   │   │   │   │   │   │      │   │Vl+│ *Knobs
     * ├────┬───┴┬──┴─┬─┴───┴───┴───┴───┴───┴──┬┴──┬┴──┬┴──┬───┼───┼───┼───┬───┐
     * │    │    │    │                        │Mut│   │   │   │   │Vl-│   │   │
     * └────┴────┴────┴────────────────────────┴───┴───┴───┴───┴───┴───┴───┴───┘
     */
    [_FN] = LAYOUT_65_ansi(
        _______, KC_F1,   KC_F2,   KC_F3,   KC_F4,   KC_F5,   KC_F6,   KC_F7,   KC_F8,   KC_F9,   KC_F10,  KC_F11,  KC_F12,  _______, _______,
        _______, _______, _______, _______, _______, _______, _______, _______, _______, _______, _______, KC_PSCR, KC_SCRL, KC_PAUS, KC_HOME,
        _______, _______, _______, _______, _______, _______, _______, _______, _______, _______, _______, KC_INS,           _______, KC_END,
        _______,          _______, _______, _______, _______, _______, _______, _______, _______, _______, _______, _______, _______, KC_VOLU,
        _______, _______, _______,                            _______,                   KC_MUTE, _______, KC_RGUI, _______, _______, KC_VOLD, _______, _______
    )
};


#if defined(ENCODER_MAP_ENABLE)
const uint16_t PROGMEM encoder_map[][NUM_ENCODERS][NUM_DIRECTIONS] = {
    [_BASE] = {ENCODER_CCW_CW(KC_VOLD, KC_VOLU),
               ENCODER_CCW_CW(KC_LEFT, KC_RGHT)},
    [_FN] = {ENCODER_CCW_CW(KC_BRID, KC_BRIU),
             ENCODER_CCW_CW(KC_MPRV, KC_MNXT)},
};
#endif

#ifdef OLED_ENABLE
bool oled_task_user(void) {
    oled_write_P(PSTR("sheaf65\n"), false);
    oled_write_P(PSTR("Layer: "), false);
    
    switch (get_highest_layer(layer_state)) {
        
        case _BASE:
            oled_write_P(PSTR("BASE\n"), false);
            break;

        case _FN:
            oled_write_P(PSTR("FUNC\n"), false);
            break;
        
        default:
            oled_write_P(PSTR("???\n"),  false);
            break;
    }

    led_t led_state = host_keyboard_led_state();
    oled_write_P(led_state.num_lock ? PSTR("NUM ") : PSTR("    "), false);
    oled_write_P(led_state.caps_lock ? PSTR("CAP ") : PSTR("    "), false);
    oled_write_P(led_state.scroll_lock ? PSTR("SCR ") : PSTR("    "), false);

    return false;
}
#endif

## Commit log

2026-04-08 inital commit at 19h lol
    [keyboooard.kicad_pcb, keyboooard.kicad_sch]
2026-04-13 add qmk firmware
    [bom.csv, keyboooard.kicad_pcb, keyboooard.kicad_sch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]
2026-04-13 update readme and keymap
    [keyboooard.kicad_sch]
2026-04-13 update pcb mounting hole 11
    [Assembly.step, Backplate.step, KeyboardPlate.step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]
2026-04-14 final update: cad, zine page, bom
    [Backplate.step, KeyboardPlate.step, SwitchPlate.step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]
2026-04-24 update: add keyboard feet, update CAD models, update BOM
    [Backplate.step, Backplate_3DP.step, KeyboardPlate.step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]
2026-04-24 TTC PY V2 hotswap sockets
    [bom.csv, bom.xlsx]
2026-04-24 update prices
    [bom.csv, bom.xlsx]
2026-04-25 tiny mistake fixed
    [sheaf65.kicad_sch]
2026-05-03 add printing to BOM
    [bom.csv, bom.xlsx]
2026-05-31 update GND and clean routes
    [bom.csv, designators.csv, positions.csv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]
